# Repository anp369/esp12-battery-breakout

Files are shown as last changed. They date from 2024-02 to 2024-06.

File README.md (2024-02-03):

# esp12-breakout

This project provides different variants for breakout boards 
to use with the ESP-12 modules featuring an ESP8266.

It features the following boards:
## [simple breakout](res/simple-breakout.md)  
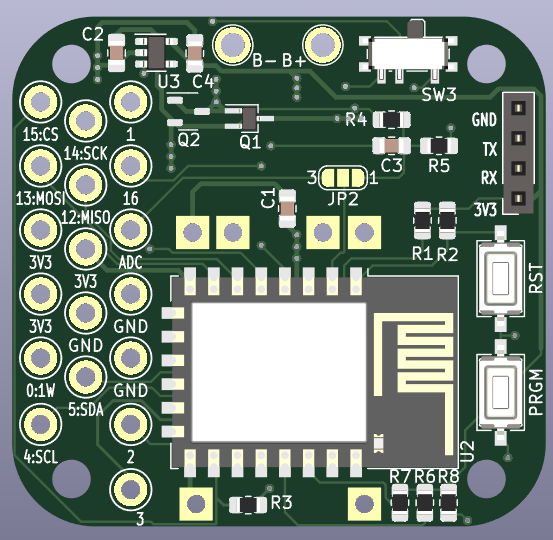
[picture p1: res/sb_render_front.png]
     
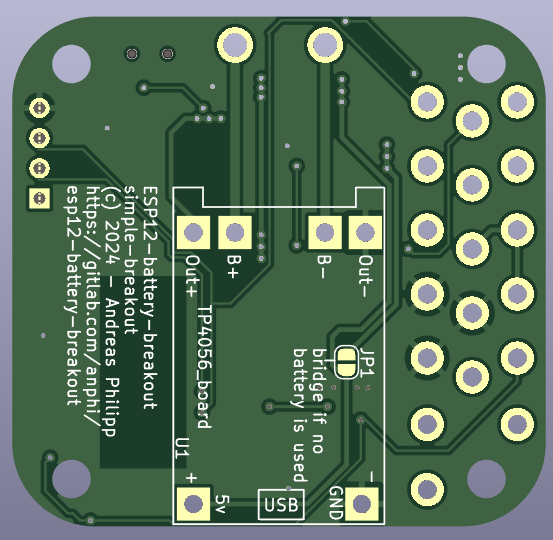
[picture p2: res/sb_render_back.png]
     

   This just exposes some all available
   GPIO pins on this board to pads on the front where you can solder sensors
   or other peripherals to. It has the dimensions 45*43 mm to perfectly
   fit in [this](https://www.reichelt.de/sensorgehaeuse-51x51x25-5-mm-massiv-weiss-cb-rs03swh-p317702.html) small sensor case.  
   It has an TP4056 board piggy backed to allow for battery powered applications.

## [esp carrier + daughterboard](res/stackable.md)  
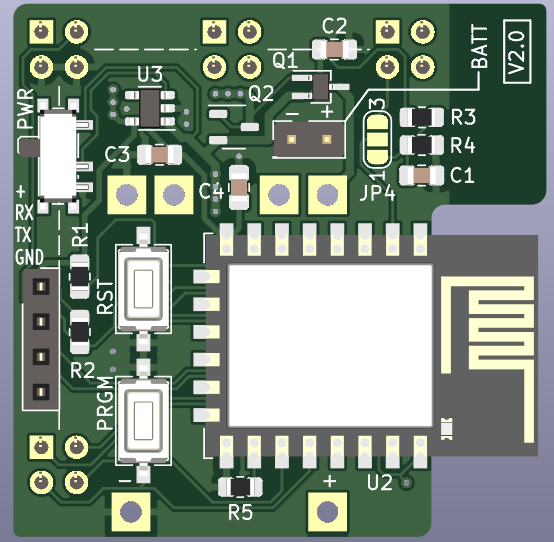
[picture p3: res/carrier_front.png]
     
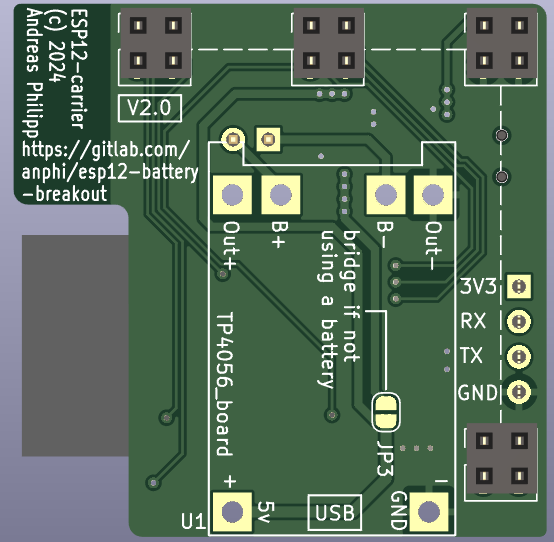
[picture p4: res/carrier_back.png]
     
   For more complex builds you have the possibility to stack two board on each other.
   The carrier is readiliy designed and fits into the lower right corner of the
   board. Using the template in the provided footprint library you can design
   a matching daugtherboard which fits your needs. This gets mounted in the 
   case and the carrier board gets plugged in on tip of it.

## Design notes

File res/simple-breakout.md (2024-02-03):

### Rendered board
<p float="left">
  
  
</p>

The whole board only measures 45 mm  * 43 mm.
Height depends on whether you use a battery and on the sensors you are using.

### Features
* Dimensions: W * H : 45 mm * 43 mm
* Input voltage: 3.0 < V_in < 5.5
* metal pads for reset and programming mode
* TP4056 based charging and protection circuit for LiOn/LiPo batteries
* integrated 3,3 V LDO voltage regultor
* optional pullup resistors for busses like I²C and OneWire
* Programming via pin header
### Assembly
There are some things to consider depending if you use a battery or
a power supply to power this project.
The voltage regulator only can deliver about 500 mA.
Make sure to not draw to much current with any additional sensors.

##### Battery
1. Check that your battery supports the selected charging current of the
   charging circuit. This can be set by a resistor. See the [datasheet](https://dlnmh9ip6v2uc.cloudfront.net/datasheets/Prototyping/TP4056.pdf) for more 
   information on which resistor value to set.
2. Make sure to populate Q1 and Q2 to switch to the power supply
   while plugged in to prevent charging and powering the circuit by battery
   at the same time. This is not supported by the charger and should be
   avoided.
3. Solder your battery directly to the battery terminals on the top.

##### Power supply
1. Short JP3 and don't populate Q1, Q2 and U1.  
   This makes connection between the
   `+` pad and the supply rail.
2. Connect your power supply to `+` and `-`. (left contact pads on the backside image)

##### Pullup Resistors
1. `R6`, `R7`, `R8` can be populated with a 4,7 k resistor to provide onboard pullup
   resistance for some busses like I²C.  
   Only populate if you want to use these pins for a bus.

### Programming
1. Connect to the UART header with your favorite 3,3 V programmer.
2. Short `PRGM` and `RST` jumpers with a metal object to set the ESP into
   bootloader mode. Now you can start the programming process. 
   (`esptool` or directly from `esphome`)

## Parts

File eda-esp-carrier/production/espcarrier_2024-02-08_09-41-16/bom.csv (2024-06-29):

Designator | Footprint | Quantity | Value | LCSC Part #
C1, C4 | 0805 | 2 | 100n
C2, C3 | 0805 | 2 | 1u
J1 | PinHeader_2x01_P2.54mm_Vertical | 1 | BATT
J2 | carrier-template | 1 | ~
J3 | PinSocket_1x04_P2.54mm_Vertical | 1 | DEBUG
JP3 | SolderJumper-2_P1.3mm_Open_RoundedPad1.0x1.5mm | 1 | no battery bridge
JP4 | SolderJumper-3_P1.3mm_Open_RoundedPad1.0x1.5mm_NumberLabels | 1 | ADC_SRC
Q1 | SOT-323_SC-70_Handsoldering | 1 | PMF170XP
Q2 | SOT-23-3 | 1 | DMN2310U
R1, R2, R5 | 0805 | 3 | 10k
R3 | 0805 | 1 | 1M
R4 | 0805 | 1 | 220k
SW1 | SW_SPDT_PCM12 | 1 | PWR
SW2 | SW_Tactile_SPST_NO_Straight_CK_PTS636Sx25SMTRLFS | 1 | RST
SW3 | SW_Tactile_SPST_NO_Straight_CK_PTS636Sx25SMTRLFS | 1 | PRGM
U1 | TP4056-18650 | 1 | TP4056_board
U2 | ESP-12E | 1 | ESP-12E
U3 | SOT-23-5 | 1 | TLV75533PDBV

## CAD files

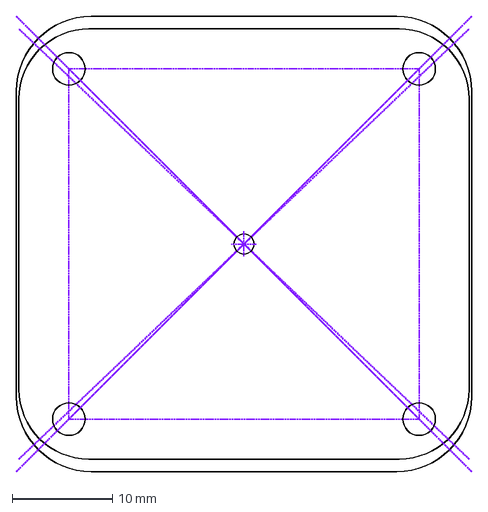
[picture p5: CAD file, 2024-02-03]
cad-drawings/both-edge-cuts.dxf
45.5 x 45.5 mm

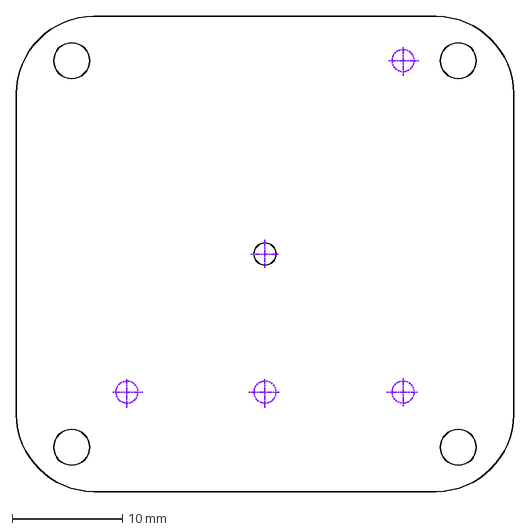
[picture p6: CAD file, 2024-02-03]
cad-drawings/daughterboard.dxf
45.0 x 43.0 mm

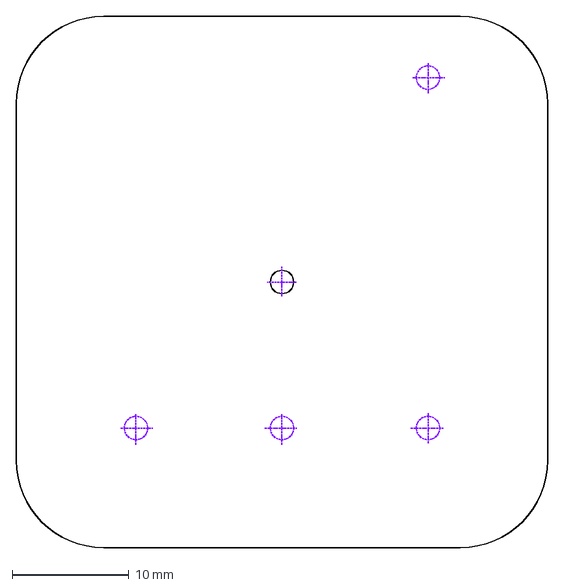
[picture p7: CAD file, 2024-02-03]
cad-drawings/carrier.dxf
45.5 x 45.5 mm

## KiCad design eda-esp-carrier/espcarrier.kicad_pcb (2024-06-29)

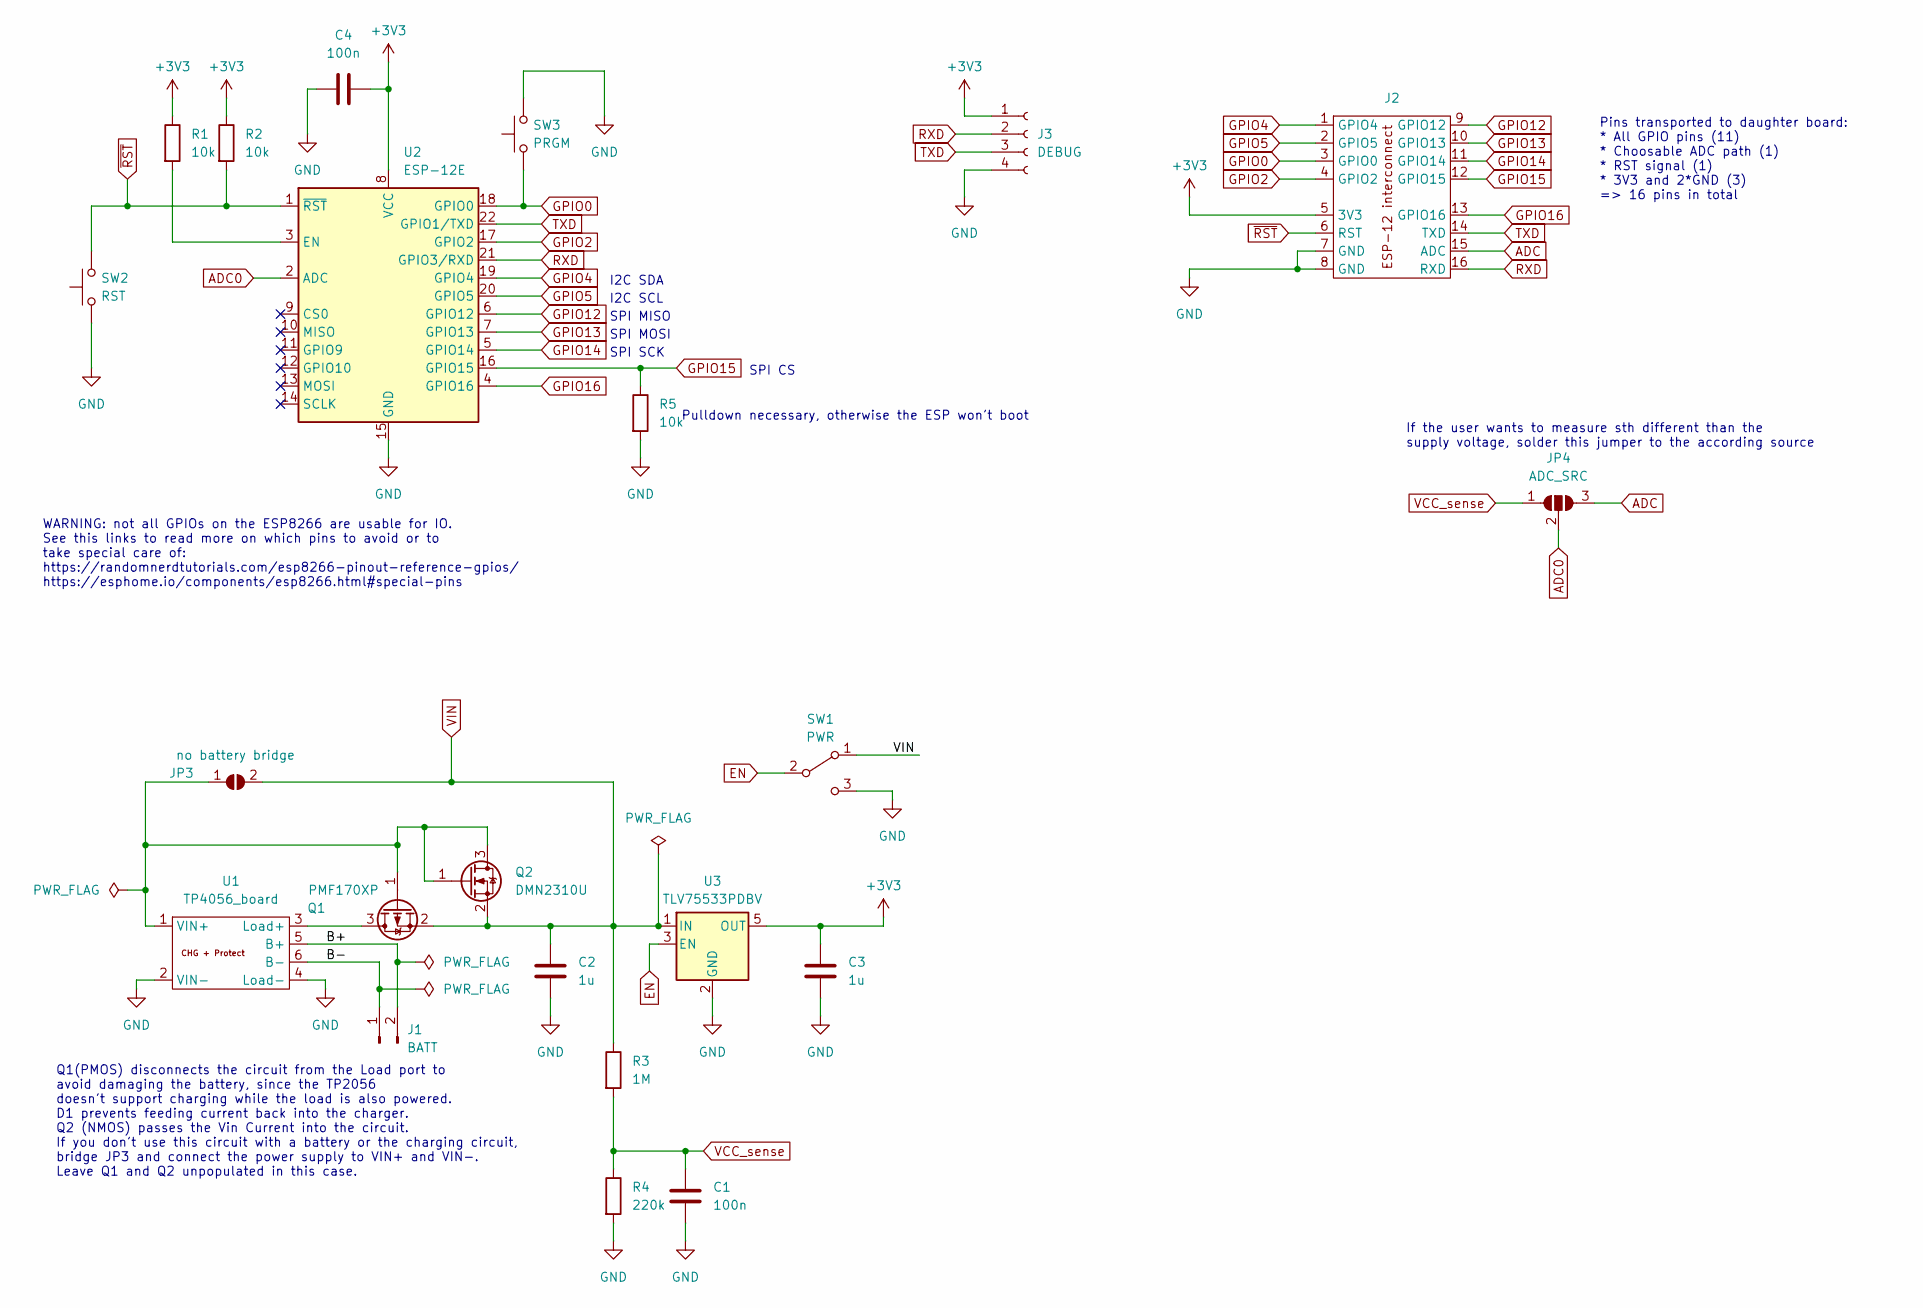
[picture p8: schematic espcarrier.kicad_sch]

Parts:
C1, C4: 100n; C_0805_2012Metric_Pad1.18x1.45mm_HandSolder
C2, C3: 1u; C_0805_2012Metric_Pad1.18x1.45mm_HandSolder
J1: BATT; PinHeader_2x01_P2.54mm_Vertical
J2: carrier-template
J3: DEBUG; PinSocket_1x04_P2.54mm_Vertical
JP3: no battery bridge; SolderJumper-2_P1.3mm_Open_RoundedPad1.0x1.5mm
JP4: ADC_SRC; SolderJumper-3_P1.3mm_Open_RoundedPad1.0x1.5mm_NumberLabels
Q1: PMF170XP; SOT-323_SC-70_Handsoldering
Q2: DMN2310U; SOT-23-3
R1, R2, R5: 10k; R_0805_2012Metric_Pad1.20x1.40mm_HandSolder
R3: 1M; R_0805_2012Metric_Pad1.20x1.40mm_HandSolder
R4: 220k; R_0805_2012Metric_Pad1.20x1.40mm_HandSolder
SW1: PWR; SW_SPDT_PCM12
SW2: RST; SW_Tactile_SPST_NO_Straight_CK_PTS636Sx25SMTRLFS
SW3: PRGM; SW_Tactile_SPST_NO_Straight_CK_PTS636Sx25SMTRLFS
U1: TP4056_board; TP4056-18650
U2: ESP-12E
U3: TLV75533PDBV; SOT-23-5

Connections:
+3V3: C3.1, C4.2, J2.5 (3V3), J3.1, R1.1, R2.1, U2.8 (VCC), U3.5 (OUT)
/B+: J1.2, U1.5 (B+)
/B-: J1.1, U1.6 (B-)
ADC: J2.15 (ADC), JP4.3 (B)
ADC0: JP4.2 (C), U2.2 (ADC)
EN: SW1.2 (B), U3.3 (EN)
GND: C1.2, C2.2, C3.2, C4.1, J2.7 (GND), J2.8 (GND), J3.4, R4.2, R5.2, SW1.3 (C), SW2.1, SW3.2, U1.2 (VIN-), U1.4 (Load-), U2.15 (GND), U3.2 (GND)
GPIO0: J2.3 (GPIO0), SW3.1, U2.18 (GPIO0)
GPIO2: J2.4 (GPIO2), U2.17 (GPIO2)
GPIO4: J2.1 (GPIO4), U2.19 (GPIO4)
GPIO5: J2.2 (GPIO5), U2.20 (GPIO5)
GPIO12: J2.9 (GPIO12), U2.6 (GPIO12)
GPIO13: J2.10 (GPIO13), U2.7 (GPIO13)
GPIO14: J2.11 (GPIO14), U2.5 (GPIO14)
GPIO15: J2.12 (GPIO15), R5.1, U2.16 (GPIO15)
GPIO16: J2.13 (GPIO16), U2.4 (GPIO16)
unnamed: JP3.1 (A), Q1.1 (G), Q2.1 (G), Q2.3 (D), U1.1 (VIN+)
unnamed: Q1.3 (D), U1.3 (Load+)
unnamed: R1.2, U2.3 (EN)
RXD: J2.16 (RXD), J3.2, U2.21 (GPIO3/RXD)
TXD: J2.14 (TXD), J3.3, U2.22 (GPIO1/TXD)
VCC_sense: C1.1, JP4.1 (A), R3.2, R4.1
VIN: C2.1, JP3.2 (B), Q1.2 (S), Q2.2 (S), R3.1, SW1.1 (A), U3.1 (IN)
~RST: J2.6 (RST), R2.2, SW2.2, U2.1 (~RST)

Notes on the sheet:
I2C SDA
Pulldown necessary, otherwise the ESP won't boot
Q1(PMOS) disconnects the circuit from the Load port to avoid damaging the battery, since the TP2056 doesn't support charging while the load is also powered. D1 prevents feeding current back into the charger. Q2 (NMOS) passes the Vin Current into the circuit. If you don't use this circuit with a bat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
SPI CS
If the user wants to measure sth different than the supply voltage, solder this jumper to the according source
Pins transported to daughter board: * All GPIO pins (11) * Choosable ADC path (1) * RST signal (1) * 3V3 and 2*GND (3) => 16 pins in total
SPI MISO
I2C SCL
SPI MOSI
WARNING: not all GPIOs on the ESP8266 are usable for IO. See this links to read more on which pins to avoid or to take special care of: https://randomnerdtutorials.com/esp8266-pinout-reference-gpios/ https://esphome.io/components/esp8266.html#special-pins
SPI SCK

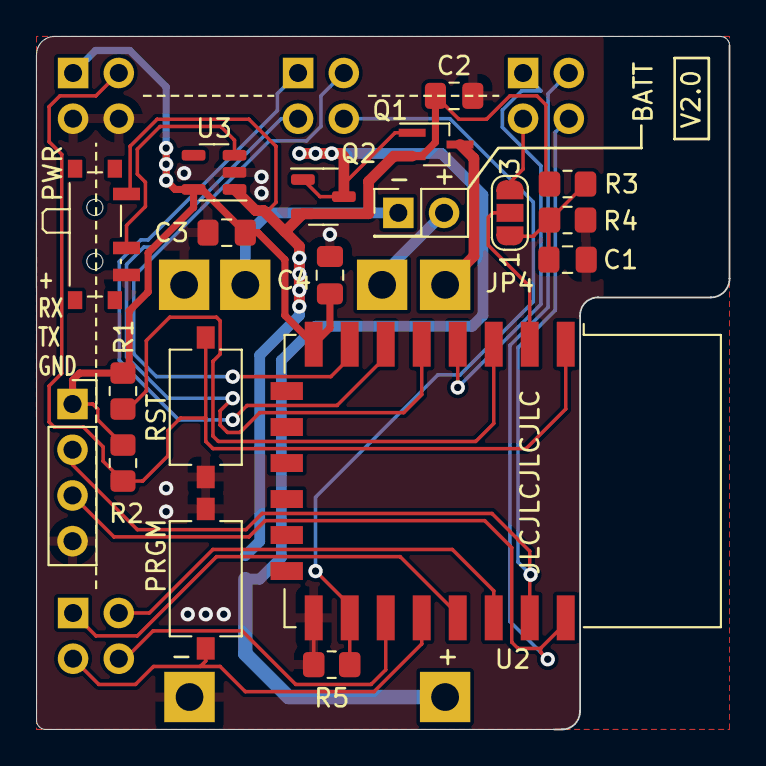
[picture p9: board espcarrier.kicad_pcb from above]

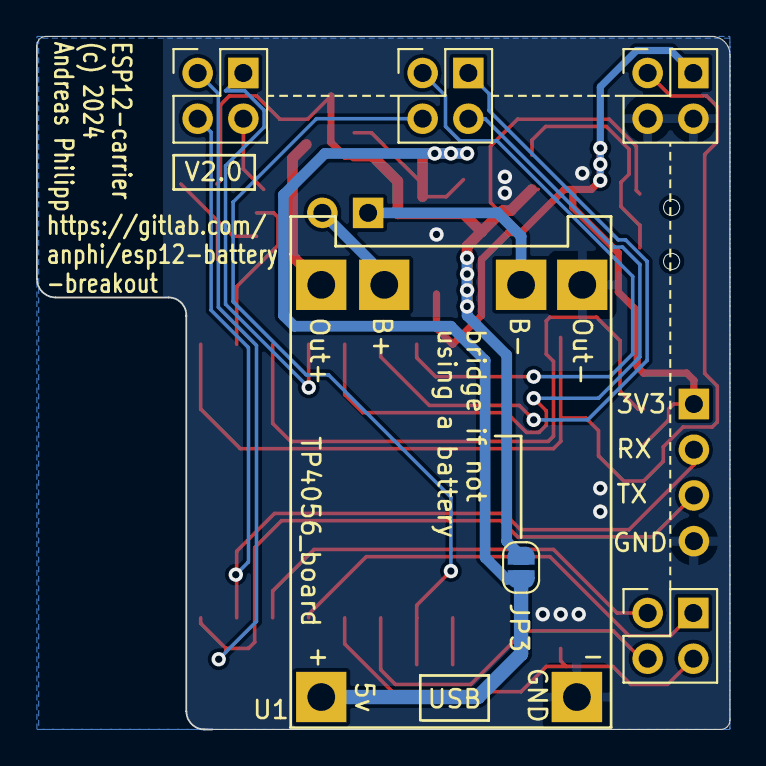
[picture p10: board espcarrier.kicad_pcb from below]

Board: 2 copper layers, 38.5 x 38.5 mm, 22 parts (2 on the bottom side), 24 nets.

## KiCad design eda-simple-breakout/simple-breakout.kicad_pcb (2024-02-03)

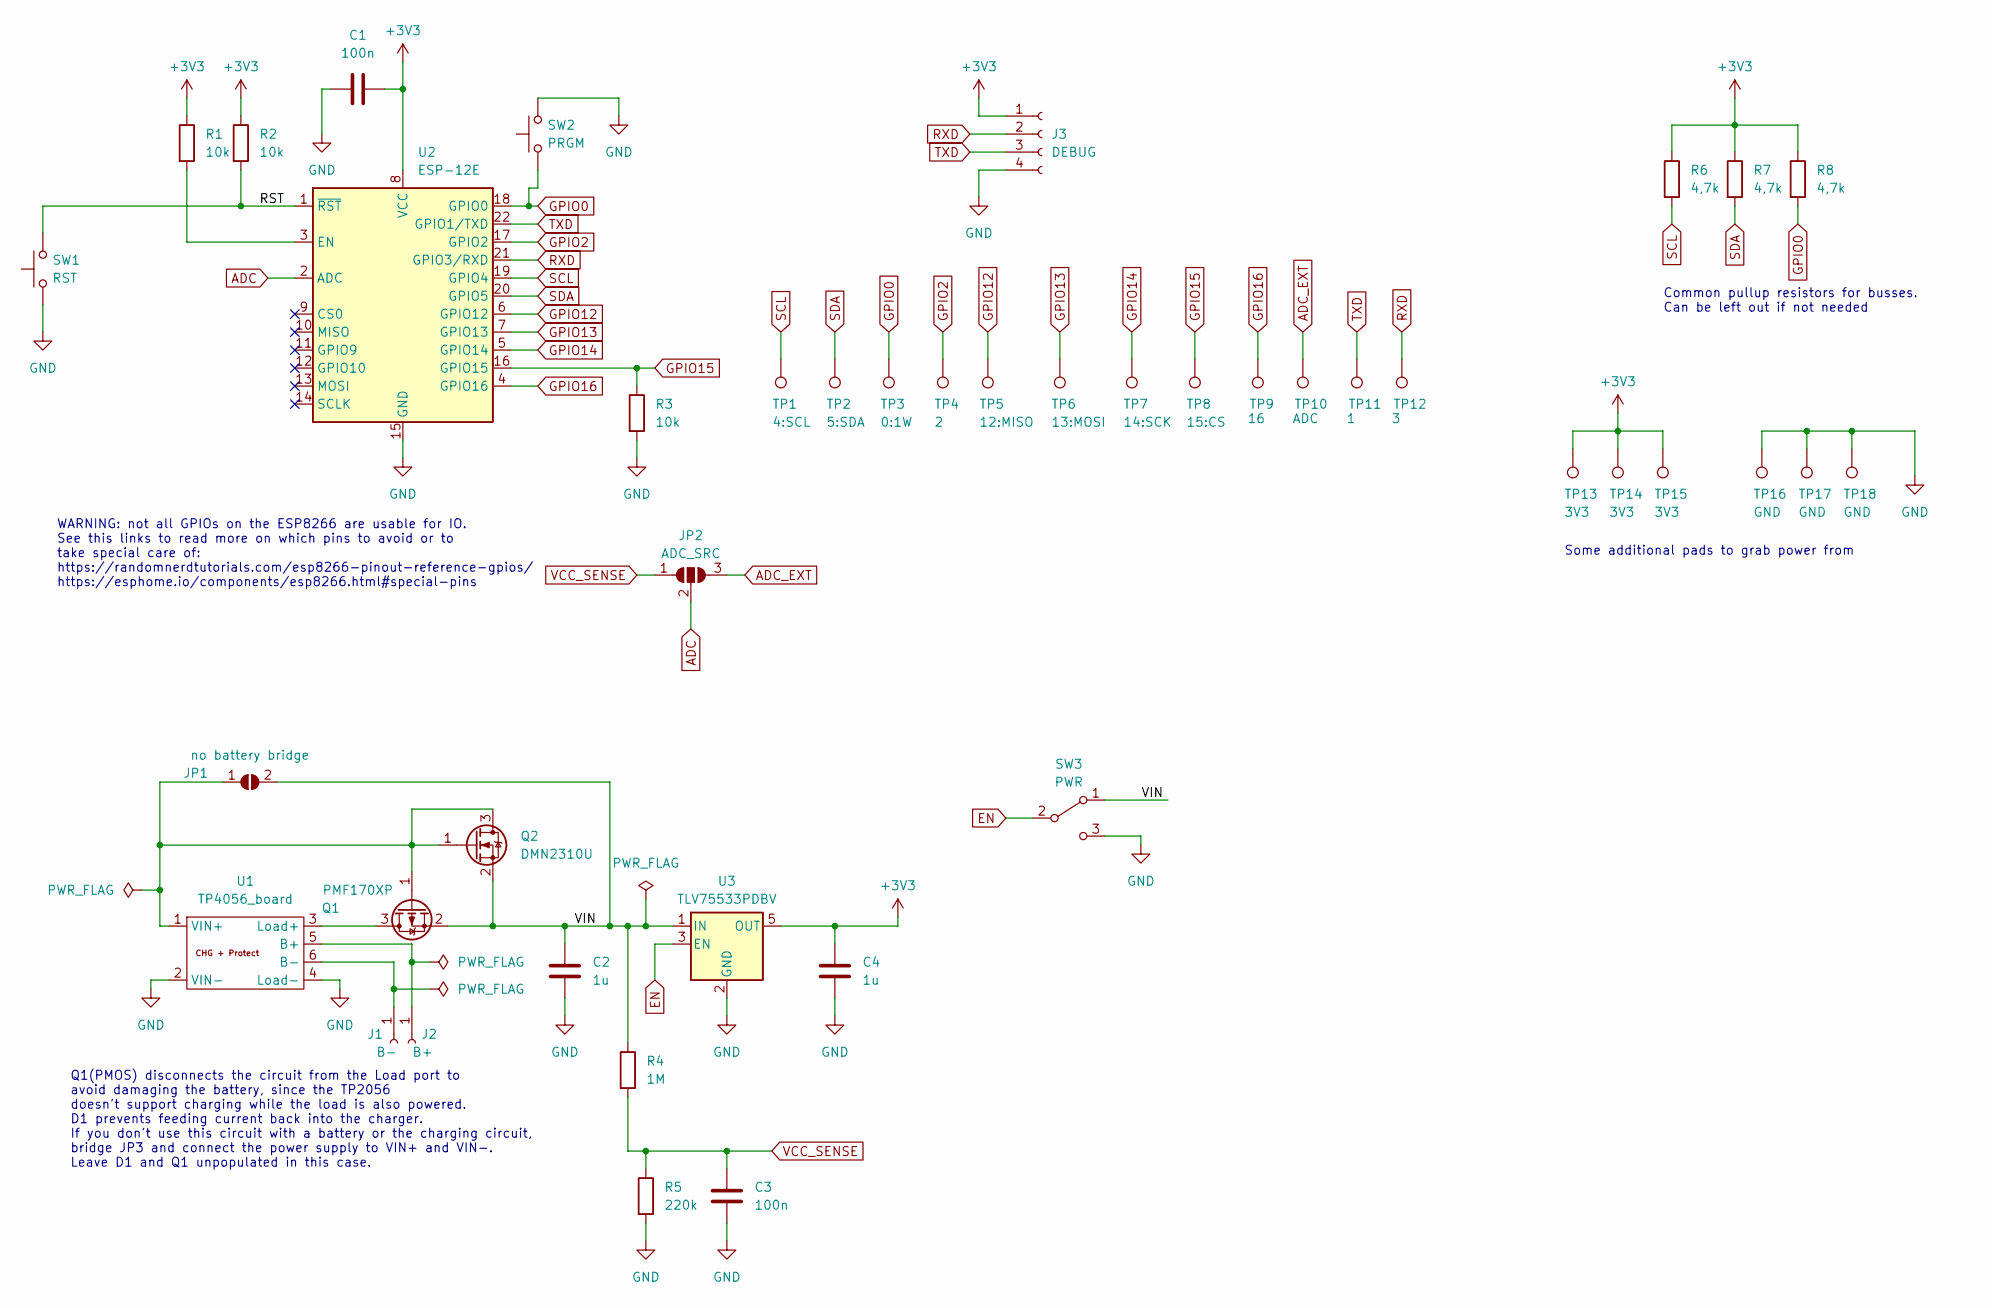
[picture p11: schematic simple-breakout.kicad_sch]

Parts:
C1, C3: 100n; C_0805_2012Metric_Pad1.18x1.45mm_HandSolder
C2, C4: 1u; C_0805_2012Metric_Pad1.18x1.45mm_HandSolder
J1: B-; TestPoint_Plated_Hole_D2.0mm
J2: B+; TestPoint_Plated_Hole_D2.0mm
J3: DEBUG; PinSocket_1x04_P2.54mm_Vertical
JP1: no battery bridge; SolderJumper-2_P1.3mm_Open_RoundedPad1.0x1.5mm
JP2: ADC_SRC; SolderJumper-3_P1.3mm_Open_RoundedPad1.0x1.5mm_NumberLabels
Q1: PMF170XP; SOT-323_SC-70_Handsoldering
Q2: DMN2310U; SOT-23-3
R1, R2, R3: 10k; R_0805_2012Metric_Pad1.20x1.40mm_HandSolder
R4: 1M; R_0805_2012Metric_Pad1.20x1.40mm_HandSolder
R5: 220k; R_0805_2012Metric_Pad1.20x1.40mm_HandSolder
R6, R7, R8: 4,7k; R_0805_2012Metric_Pad1.20x1.40mm_HandSolder
SW1: RST; SW_Tactile_SPST_NO_Straight_CK_PTS636Sx25SMTRLFS
SW2: PRGM; SW_Tactile_SPST_NO_Straight_CK_PTS636Sx25SMTRLFS
SW3: PWR; SW_SPDT_PCM12
TP1: 4:SCL; TestPoint_Keystone_5005-5009_Compact
TP2: 5:SDA; TestPoint_Keystone_5005-5009_Compact
TP3: 0:1W; TestPoint_Keystone_5005-5009_Compact
TP4: 2; TestPoint_Keystone_5005-5009_Compact
TP5: 12:MISO; TestPoint_Keystone_5005-5009_Compact
TP6: 13:MOSI; TestPoint_Keystone_5005-5009_Compact
TP7: 14:SCK; TestPoint_Keystone_5005-5009_Compact
TP8: 15:CS; TestPoint_Keystone_5005-5009_Compact
TP9: 16; TestPoint_Keystone_5005-5009_Compact
TP10: ADC; TestPoint_Keystone_5005-5009_Compact
TP11: 1; TestPoint_Keystone_5005-5009_Compact
TP12: 3; TestPoint_Keystone_5005-5009_Compact
TP13, TP14, TP15: 3V3; TestPoint_Keystone_5005-5009_Compact
TP16, TP17, TP18: GND; TestPoint_Keystone_5005-5009_Compact
U1: TP4056_board; TP4056-18650
U2: ESP-12E
U3: TLV75533PDBV; SOT-23-5

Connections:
+3V3: C1.2, C4.1, J3.1, R1.1, R2.1, R6.1, R7.1, R8.1, TP13.1, TP14.1, TP15.1, U2.8 (VCC), U3.5 (OUT)
/RST: R2.2, SW1.2, U2.1 (~RST)
/VIN: C2.1, JP1.2 (B), Q1.2 (S), Q2.2 (S), R4.1, SW3.1 (A), U3.1 (IN)
ADC: JP2.2 (C), U2.2 (ADC)
ADC_EXT: JP2.3 (B), TP10.1
EN: SW3.2 (B), U3.3 (EN)
GND: C1.1, C2.2, C3.2, C4.2, J3.4, R3.2, R5.2, SW1.1, SW2.2, SW3.3 (C), TP16.1, TP17.1, TP18.1, U1.2 (VIN-), U1.4 (Load-), U2.15 (GND), U3.2 (GND)
GPIO0: R8.2, SW2.1, TP3.1, U2.18 (GPIO0)
GPIO2: TP4.1, U2.17 (GPIO2)
GPIO12: TP5.1, U2.6 (GPIO12)
GPIO13: TP6.1, U2.7 (GPIO13)
GPIO14: TP7.1, U2.5 (GPIO14)
GPIO15: R3.1, TP8.1, U2.16 (GPIO15)
GPIO16: TP9.1, U2.4 (GPIO16)
unnamed: J1.1, U1.6 (B-)
unnamed: J2.1, U1.5 (B+)
unnamed: JP1.1 (A), Q1.1 (G), Q2.1 (G), Q2.3 (D), U1.1 (VIN+)
unnamed: Q1.3 (D), U1.3 (Load+)
unnamed: R1.2, U2.3 (EN)
RXD: J3.2, TP12.1, U2.21 (GPIO3/RXD)
SCL: R6.2, TP1.1, U2.19 (GPIO4)
SDA: R7.2, TP2.1, U2.20 (GPIO5)
TXD: J3.3, TP11.1, U2.22 (GPIO1/TXD)
VCC_SENSE: C3.1, JP2.1 (A), R4.2, R5.1

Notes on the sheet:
Q1(PMOS) disconnects the circuit from the Load port to avoid damaging the battery, since the TP2056 doesn't support charging while the load is also powered. D1 prevents feeding current back into the charger. If you don't use this circuit with a battery or the charging circuit, bridge JP3 and connec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
Some additional pads to grab power from
Common pullup resistors for busses. Can be left out if not needed
WARNING: not all GPIOs on the ESP8266 are usable for IO. See this links to read more on which pins to avoid or to take special care of: https://randomnerdtutorials.com/esp8266-pinout-reference-gpios/ https://esphome.io/components/esp8266.html#special-pins

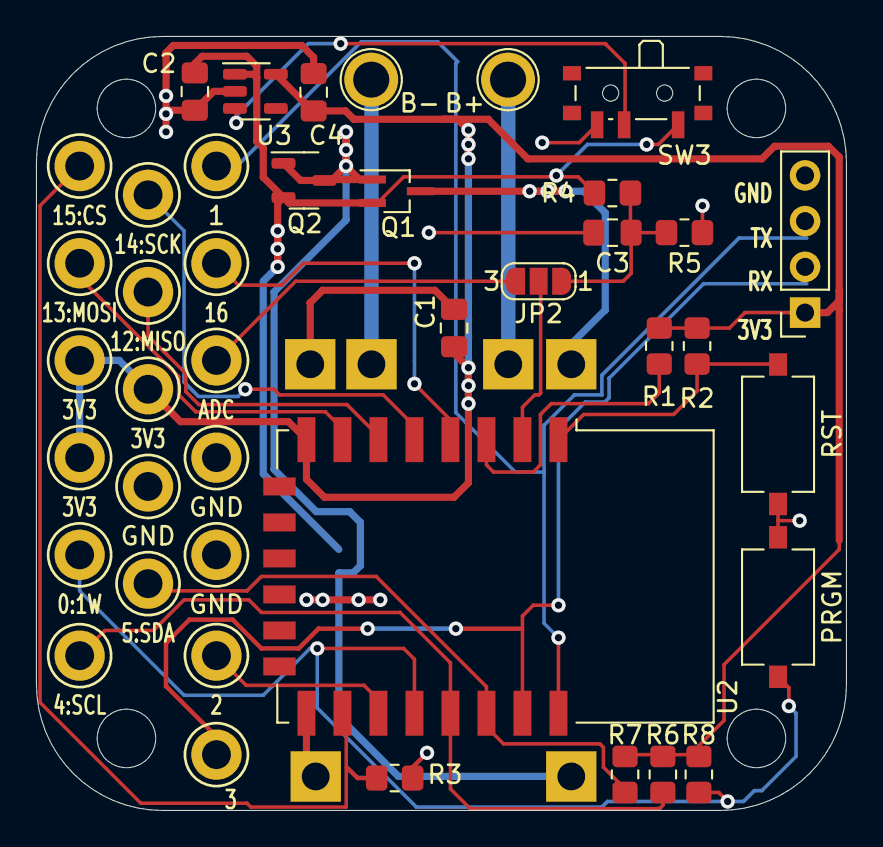
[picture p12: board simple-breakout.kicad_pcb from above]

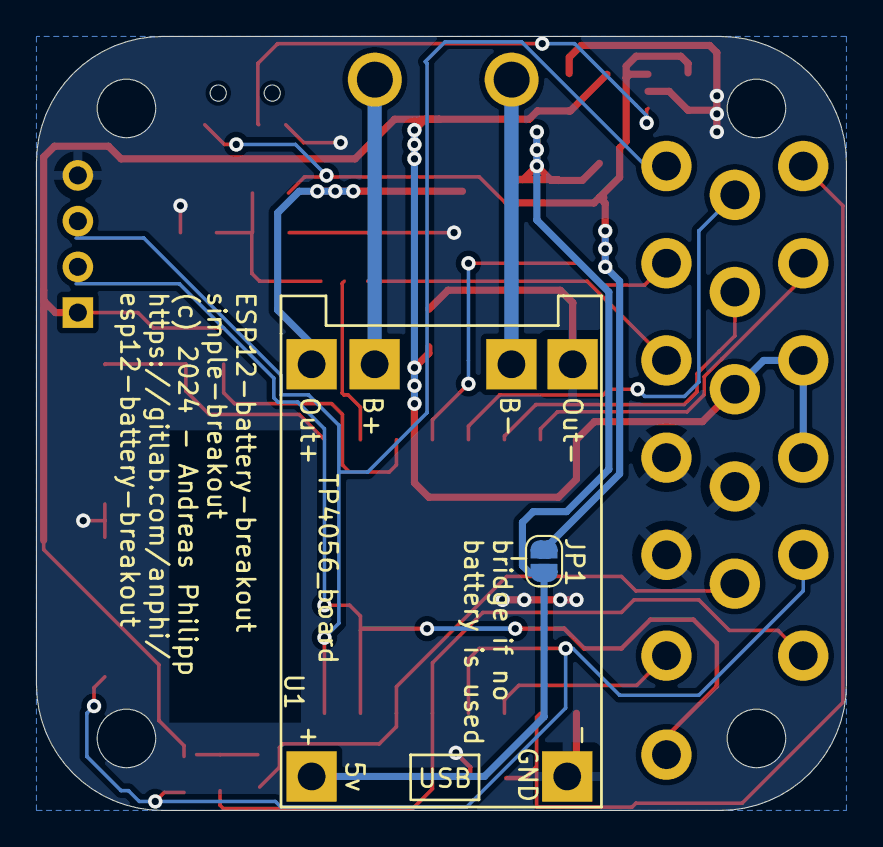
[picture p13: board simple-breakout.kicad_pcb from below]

Board: 2 copper layers, 45.0 x 43.0 mm, 43 parts (2 on the bottom side), 24 nets.

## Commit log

2023-11-06 Check in first version of layout
    [esp12-therm.kicad_pcb, esp12-therm.kicad_sch]
2023-11-09 Add JLC labels and silkscreen update, make board round
    [esp12-therm.kicad_pcb, esp12-therm.kicad_sch]
2023-11-09 add kicad lock files to ignore
2023-11-09 Add Voltage regulator to board
    [esp12-therm.kicad_pcb, esp12-therm.kicad_sch]
2023-12-07 Change input MOSFET to an available one
    [esp12-therm.kicad_pcb, esp12-therm.kicad_sch]
2023-12-08 * Adapt footprints to new MOSFET * Place battery bypass solder jumper
    [esp12-therm.kicad_pcb, esp12-therm.kicad_sch]
2024-01-14 Redesign to make it a fully breakout board: * Add pads for all pins * shrink board ad far as possible * place pull up resistors close to each other at the back * replace nmos with a schottky diode
    [esp12-therm.kicad_pcb, esp12-therm.kicad_sch]
2024-02-03 Complete redo: * make board bigger to fit sensor case * Add simple breakout to just breakout all GPIOs * Add carrier board which stacks on daughterboards * Add templates and library items for creatin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
    [both-edge-cuts.dxf, carrier.dxf, daughterboard.dxf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]
2024-06-26 move some component
    [bom.csv, designators.csv, espcarrier.kicad_pcb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]
2024-06-26 work on RF rework
    [espcarrier.kicad_pcb]
2024-06-29 finish rf friendlier desgin
    [espcarrier.kicad_pcb, espcarrier.kicad_sch]
2024-06-29 add bom and production folders to gitignore

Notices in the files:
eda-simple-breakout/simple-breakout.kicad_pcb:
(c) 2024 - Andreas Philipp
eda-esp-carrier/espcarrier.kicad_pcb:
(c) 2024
